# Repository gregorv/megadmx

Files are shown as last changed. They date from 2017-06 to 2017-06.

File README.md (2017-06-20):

# megadmx
An ATmega88 based LED dimmer, strobe and fog controller.

For a small project I needed an DMX controller for a 30W-70W white LED stroboscope, a length of RGB LED tape and a relay controlling a Eurolite N10 fog machine. The circutry is based on an ATmega88 controller (hence the repository name), with cheap
FETs for dimming and a beefy FET for the strobe. Cheap 24V 3A and 12V 2A switching power supplies from ebay power the device.

## DMX Channels
The controller uses 7 DMX channels. The starting address can be set with software or a 5 pin jumper header. Therefore, without firmware flashing only 32 different addresses are possible. :/

| Channel | Function |
| :-----: | :--- |
| 1 | Tape Dimmer 0-255 |
| 2 | Tape Red 0-255 |
| 3 | Tape Green 0-255 |
| 4 | Tape Blue  0-255 |
| 5 | Tape Strobe Frequency 1-255, 0 off |
| 6 | LED Power Strobe Frequency 1-255, 0 off |
| 7 | Fog Off 0-126, Fog On 127-255 |

## Hardware Description
The mainboard is powered with +12V over a two pin connector. The supply current is used to light the LED tape. A 7805 generates the voltage for the microprocessor. A standard SP485 IC is used as DMX interface.

The PCB is designed to be home-etchable with the photo-transfer method. The PCB size can be _significantly_ reduced if a proper plated 2-layer layout is used.

### LED Tape Connection
A four pin connector is used for connecting a standard 12V LED tape with common anode. The pin layout follows the standard cabling order for this kind of tape.

| Pin | Function |
| :-: | --- |
| 1 | +12 V |
| 2 | Green |
| 3 | Red |
| 4 | Blue |

### Power Strobe Connection
The power LED strobe circuit is a IRF540N Power-MOSFET switching a screw terminal input to ground. Connect a power LED low-side equiped with a suitable power supply (read: constant current / current limited). Note: the LED flashes when the circuit is turned on, because the FET driving ciruit invertes the logic state of the processor pin. This is a nice visual feedback that the device is switched on.

### Fog Machine Connection
We use a Eurolite N10 smoke machine. It is very cheap (less than 40€), the remote control switches mains voltages for the fluid pump, making it very simple to interface the machine with a simple relay. Note that part of the circuit is live on mains voltage, use the N10 control only if you know about the risks and neccessary safety procedures.

## Software Description

Peter Flery UART library for DMX reception.

TIMER0 overflow interrupt generates 3 channel PWM for LED tape.

TIMER2 in CTC interrupt generates strobe for tape and power LED.

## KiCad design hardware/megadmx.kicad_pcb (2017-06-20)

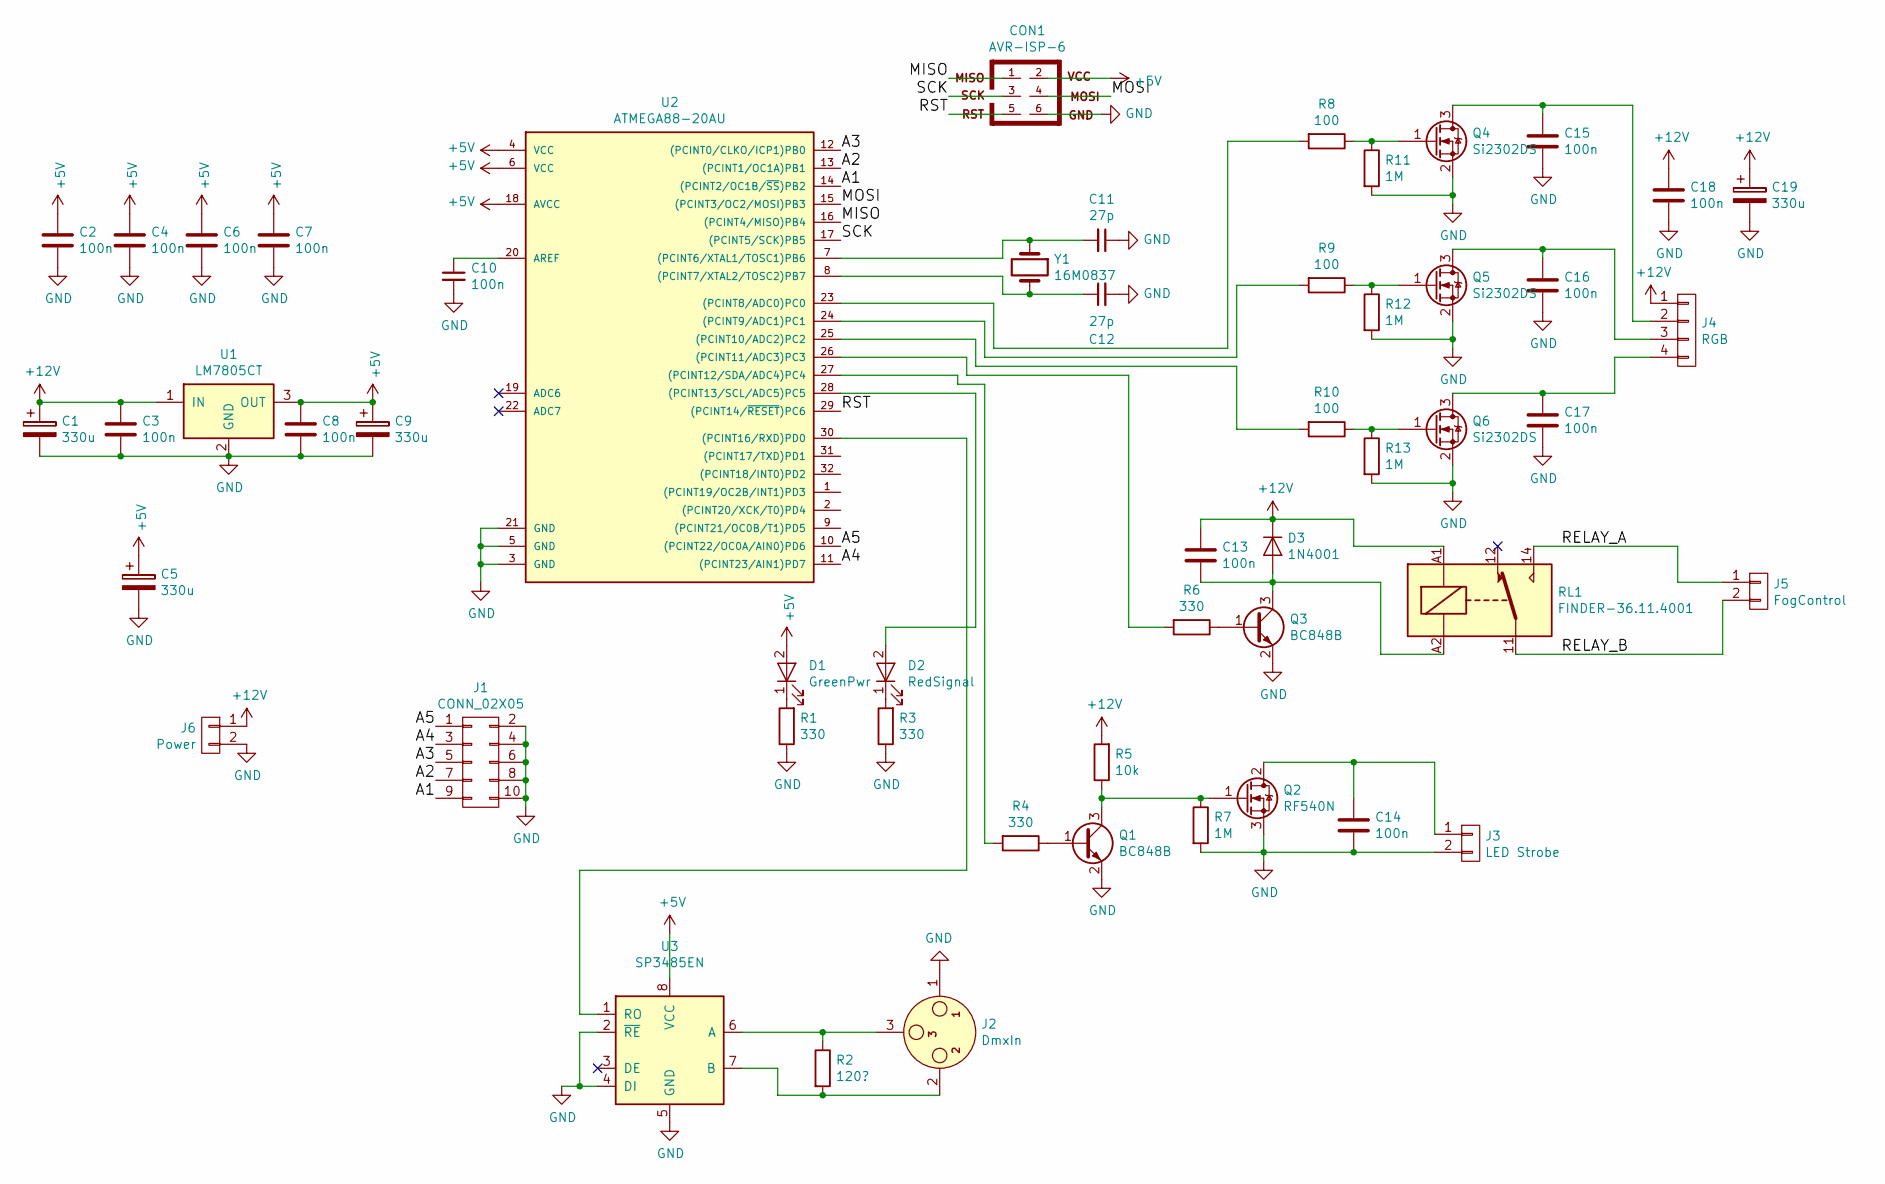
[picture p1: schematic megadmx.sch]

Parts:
C1, C5, C9, C19: 330u; CP_Elec_8x10
C2, C3, C4, C6, C7, C8, C10, C13, C14, C15, C16, C17, C18: 100n; C_0603_HandSoldering
C11, C12: 27p; C_0603_HandSoldering
CON1: AVR-ISP-6; Pin_Header_Straight_2x03_Pitch2.54mm
D1: GreenPwr; LED_D5.0mm
D2: RedSignal; LED_D5.0mm
D3: 1N4001; D_DO-35_SOD27_P5.08mm_Vertical_KathodeUp
J1: CONN_02X05; Pin_Header_Angled_2x05_Pitch2.54mm
J2: DmxIn; XLR_NC3_MAH
J3: LED Strobe; TerminalBlock_Pheonix_MKDS1.5-2pol
J4: RGB; JST_EH_B04B-EH-A_04x2.50mm_Straight
J5: FogControl; JST_EH_B02B-EH-A_02x2.50mm_Straight
J6: Power; JST_EH_B02B-EH-A_02x2.50mm_Straight
Q1, Q3: BC848B; SOT-23
Q2: RF540N; TO-220_Neutral123_Vertical_LargePads
Q4, Q5, Q6: Si2302DS; SOT-23
R1, R3, R4, R6: 330; R_0603_HandSoldering
R2: 120?; R_0603_HandSoldering
R5: 10k; R_0603_HandSoldering
R7, R11, R12, R13: 1M; R_0603_HandSoldering
R8, R9, R10: 100; R_0603_HandSoldering
RL1: FINDER-36.11.4001; Relay_Finder_series36
U1: LM7805CT; TO-220
U2: ATMEGA88-20AU; TQFP-32_7x7mm_Pitch0.8mm
U3: SP3485EN; SOIC-8_3.9x4.9mm_Pitch1.27mm
Y1: 16M0837; Crystal_SMD_HC49-SD

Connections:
+5V: C2.1, C4.1, C5.1, C6.1, C7.1, C8.1, C9.1, CON1.2, D1.2 (A), U1.3 (OUT), U2.4 (VCC), U2.6 (VCC), U2.18 (AVCC), U3.8 (VCC)
+12V: C1.1, C3.1, C13.1, C18.1, C19.1, D3.1 (K), J4.1, J6.1, R5.2, RL1.A1, U1.1 (IN)
/A1: J1.9, U2.14 ((PCINT2/OC1B/~SS~)PB2)
/A2: J1.7, U2.13 ((PCINT1/OC1A)PB1)
/A3: J1.5, U2.12 ((PCINT0/CLKO/ICP1)PB0)
/A4: J1.3, U2.11 ((PCINT23/AIN1)PD7)
/A5: J1.1, U2.10 ((PCINT22/OC0A/AIN0)PD6)
/MISO: CON1.1, U2.16 ((PCINT4/MISO)PB4)
/MOSI: CON1.4, U2.15 ((PCINT3/OC2/MOSI)PB3)
/RELAY_A: J5.1, RL1.14
/RELAY_B: J5.2, RL1.11
/RST: CON1.5, U2.29 ((PCINT14/~RESET~)PC6)
/SCK: CON1.3, U2.17 ((PCINT5/SCK)PB5)
GND: C1.2, C2.2, C3.2, C4.2, C5.2, C6.2, C7.2, C8.2, C9.2, C10.2, C11.1, C12.2, C14.1, C15.2, C16.2, C17.2, C18.2, C19.2, CON1.6, J1.2, J1.4, J1.6, J1.8, J1.10, J2.1, J3.2, J6.2, Q1.2 (E), Q2.3 (S), Q3.2 (E), Q4.2 (S), Q5.2 (S), Q6.2 (S), R1.1, R3.1, R7.2, R11.2, R12.2, R13.2, U1.2 (GND), U2.3 (GND), U2.5 (GND), U2.21 (GND), U3.2 (~RE~), U3.4 (DI), U3.5 (GND)
unnamed: C10.1, U2.20 (AREF)
unnamed: C11.2, U2.7 ((PCINT6/XTAL1/TOSC1)PB6), Y1.1
unnamed: C12.1, U2.8 ((PCINT7/XTAL2/TOSC2)PB7), Y1.2
unnamed: C13.2, D3.2 (A), Q3.3 (C), RL1.A2
unnamed: C14.2, J3.1, Q2.2 (D)
unnamed: C15.1, J4.2, Q4.3 (D)
unnamed: C16.1, J4.3, Q5.3 (D)
unnamed: C17.1, J4.4, Q6.3 (D)
unnamed: D1.1 (K), R1.2
unnamed: D2.1 (K), R3.2
unnamed: D2.2 (A), U2.28 ((PCINT13/SCL/ADC5)PC5)
unnamed: J2.2, R2.2, U3.7 (B)
unnamed: J2.3, R2.1, U3.6 (A)
unnamed: Q1.1 (B), R4.1
unnamed: Q1.3 (C), Q2.1 (G), R5.1, R7.1
unnamed: Q3.1 (B), R6.1
unnamed: Q4.1 (G), R8.1, R11.1
unnamed: Q5.1 (G), R9.1, R12.1
unnamed: Q6.1 (G), R10.1, R13.1
unnamed: R4.2, U2.27 ((PCINT12/SDA/ADC4)PC4)
unnamed: R6.2, U2.26 ((PCINT11/ADC3)PC3)
unnamed: R8.2, U2.23 ((PCINT8/ADC0)PC0)
unnamed: R9.2, U2.24 ((PCINT9/ADC1)PC1)
unnamed: R10.2, U2.25 ((PCINT10/ADC2)PC2)
unnamed: U2.30 ((PCINT16/RXD)PD0), U3.1 (RO)

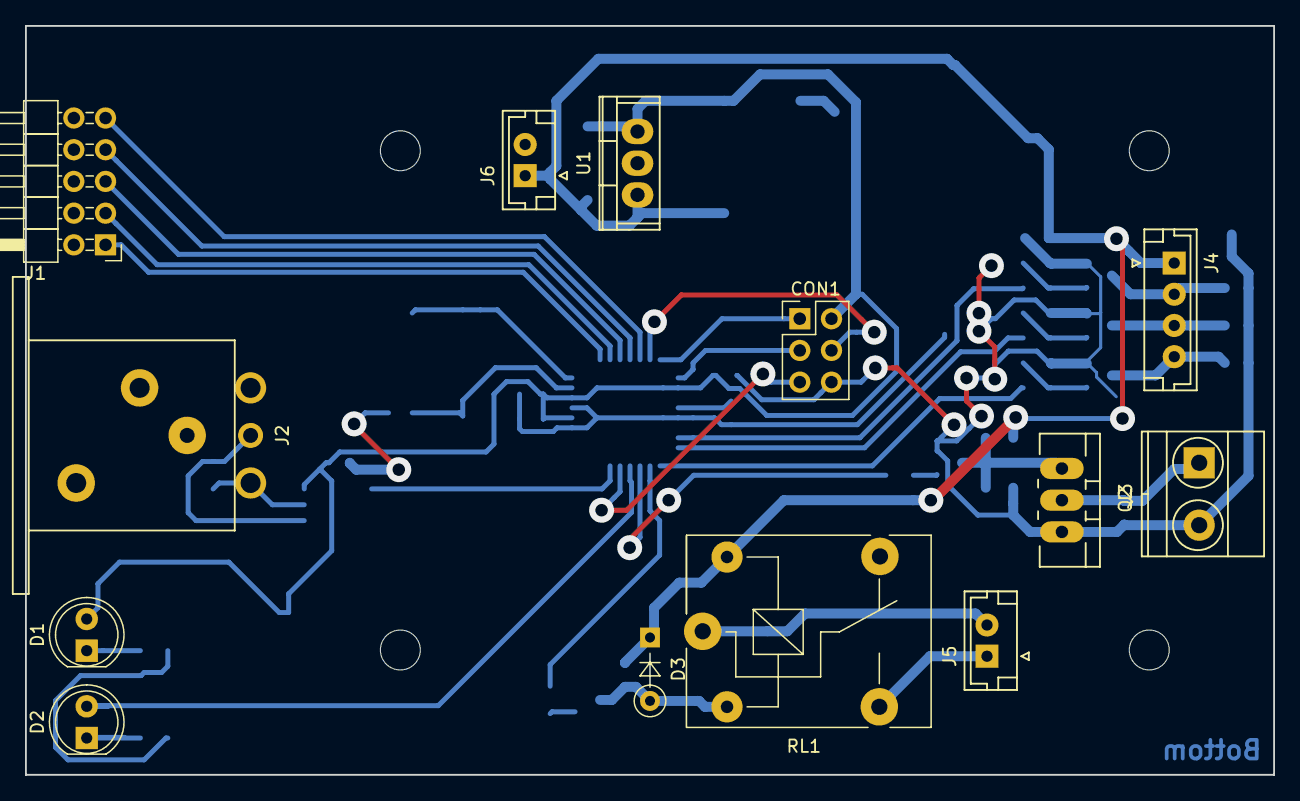
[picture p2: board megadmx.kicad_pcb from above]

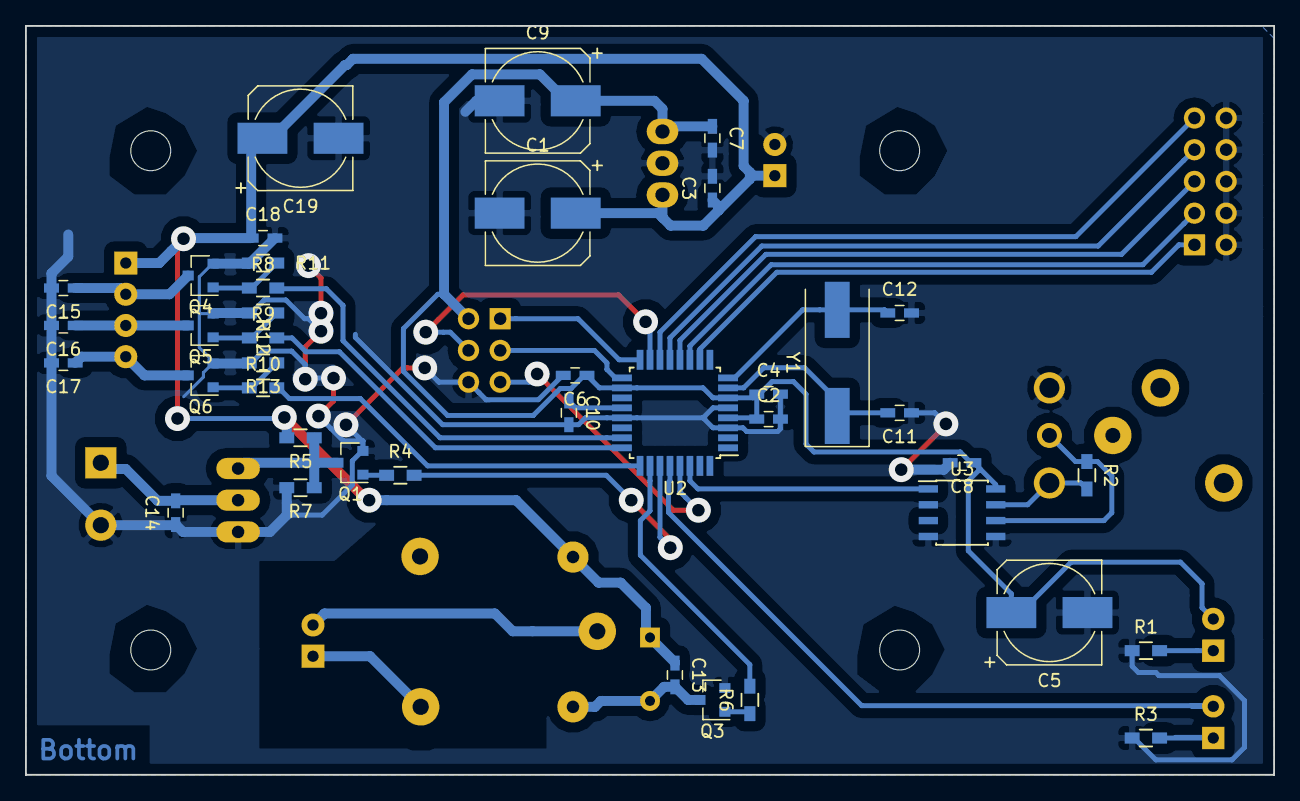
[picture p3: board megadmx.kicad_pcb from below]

Board: 2 copper layers, 100.0 x 60.0 mm, 53 parts (40 on the bottom side), 39 nets.

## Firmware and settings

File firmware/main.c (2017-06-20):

/*  MegaDMX – Atmega DMX firmware for Toilet-Control
    Copyright (C) 2017 Gregor Vollmer <git@dynamic-noise.net>

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
    You should have received a copy of the GNU General Public License
    along with this program.  If not, see <http://www.gnu.org/licenses/>.
*/
#include "main.h"
#include <util/delay.h>
#include <avr/wdt.h>
#include <util/setbaud.h>

void test(void);
void test_strobe(void);

void greetingFlash(void);

#define CHANNEL_COUNT 7

int main(void)
{
	wdt_enable(WDTO_1S);
	SIGNAL_LED_DDR |= (1 << SIGNAL_LED_PIN);
	greetingFlash();
	// test_strobe();
	// while(1) test();
	uart_init(UART_BAUD_SELECT(BAUD, F_CPU));
	dmx_addr_init();
	control_init();
	set_sleep_mode(SLEEP_MODE_IDLE);
	sei();
	uint16_t current_dmx_channel = 0;
	uint8_t package[CHANNEL_COUNT];
	for(;;) {
		unsigned int recvData = uart_getc();
		uint8_t data = (uint8_t)recvData;
		uint16_t dmx_addr = dmx_addr_read() + 1; // start frame
		if((recvData & UART_FRAME_ERROR) == UART_FRAME_ERROR) {
			current_dmx_channel = 0;
			SIGNAL_LED_TOGGLE;
		} else if((recvData & UART_BUFFER_OVERFLOW) ||
		          (recvData & UART_OVERRUN_ERROR)) {
			while(1) {}
		} else if(recvData & UART_NO_DATA) {
		} else {
			if(current_dmx_channel >= dmx_addr &&
			   current_dmx_channel < dmx_addr+CHANNEL_COUNT) {
				package[current_dmx_channel - dmx_addr] = data;
				if(current_dmx_channel == dmx_addr + CHANNEL_COUNT - 1) {
					control_ledstrip(package[0], package[1], package[2], package[3], package[4]);
					control_strobe(package[5]);
					if(package[6] > 127) {
						control_fog_on();
					} else {
						control_fog_off();
					}
				}
			}
			++current_dmx_channel;
		}
		wdt_reset();
	}
	return 0;
}

void greetingFlash(void)
{
	for(char i = 0; i < 5; ++i) {
		SIGNAL_LED_ON;
		_delay_ms(50);
	
		SIGNAL_LED_OFF;
		_delay_ms(50);
	}
}

void test(void)
{
	COLOR_LED_DDR |= (1 << COLOR_LED_RED);
	COLOR_LED_DDR |= (1 << COLOR_LED_GREEN);
	COLOR_LED_DDR |= (1 << COLOR_LED_BLUE);
	STROBE_LED_DDR |= (1 << STROBE_LED_PIN);
	FOG_RELAY_DDR |= (1 << FOG_RELAY_PIN);
	SIGNAL_LED_DDR |= (1 << SIGNAL_LED_PIN);

	COLOR_LED_OUT &= ~((1 << COLOR_LED_RED) | (1 << COLOR_LED_GREEN) | (1 << COLOR_LED_BLUE));
	FOG_RELAY_OUT &= ~(1 << FOG_RELAY_PIN);
	STROBE_LED_OUT |= (1 << STROBE_LED_PIN);
	SIGNAL_LED_OUT &= ~(1 << SIGNAL_LED_PIN);

	int time = 200;

	_delay_ms(time); wdt_reset();
	COLOR_LED_OUT |= (1 << COLOR_LED_RED);

	_delay_ms(time); wdt_reset();
	COLOR_LED_OUT |= (1 << COLOR_LED_GREEN);

	_delay_ms(time); wdt_reset();
	COLOR_LED_OUT |= (1 << COLOR_LED_BLUE);

	_delay_ms(time); wdt_reset();
	SIGNAL_LED_OUT |= (1 << SIGNAL_LED_PIN);

	_delay_ms(time); wdt_reset();
	FOG_RELAY_OUT |= (1 << FOG_RELAY_PIN);

	_delay_ms(time); wdt_reset();
	STROBE_LED_OUT &= ~(1 << STROBE_LED_PIN);
	_delay_ms(10); wdt_reset();
}

void test_strobe(void)
{
	STROBE_LED_OUT |= (1 << STROBE_LED_PIN);
	while(1) {
		_delay_ms(30); wdt_reset();
		STROBE_LED_OUT &= ~(1 << STROBE_LED_PIN);
		_delay_ms(15);
		STROBE_LED_OUT |= (1 << STROBE_LED_PIN);
	}
}

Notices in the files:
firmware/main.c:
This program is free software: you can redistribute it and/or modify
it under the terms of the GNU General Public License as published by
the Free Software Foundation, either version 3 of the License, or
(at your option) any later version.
